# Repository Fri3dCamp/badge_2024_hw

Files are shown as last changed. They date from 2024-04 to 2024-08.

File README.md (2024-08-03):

# Badge 2024 hardware
In deze Git repository kan je de ontwerpbestanden en productiedata vinden van de [Fri3d Camp](https://fri3d.be/) 2024 badge. Revisie 01 is de versie die op kamp zal uitgedeeld worden.

De badge is gebouwd rond de **Espressif [ESP32-S3-WROOM-1-N16R8](Datasheets/esp32-s3-wroom-1_wroom-1u_datasheet_en.pdf) module** met :

- 16MB flash 
- 8MB PSRAM. 
- De [ESP32-S3](Datasheets/esp32-s3_datasheet_en.pdf) dual-core Xtensa LX7 microcontroller (geklokt aan 240MHz)
- Wi-Fi (via de ESP32-S3)
- Bluetooth 5 (via de ESP32-S3)

Omdat deze microcontroller zelf een USB interface heeft is er geen nood meer om een USB serial brug te voorzien zoals op de [badge van 2022]( https://github.com/Fri3dCamp/badge-2020) en de [badge van 2018]( https://github.com/Fri3dCamp/badge). 

We hebben de badge ook uitgerust met:

- [6-assige IMU van Würth Elektronik](Datasheets/Wurth-WSEN-ISDS.pdf)
- buzzer
- veel drukknoppen
- joystick
- microSD kaart lezer
- een prachtige [2” IPS LCD met afgeronde hoeken](Datasheets/QT020JA001-A0_SPEC.pdf).

Er is opnieuw een [tweede voeding](Datasheets/xc6210.pdf) geplaatst om de Wi-Fi module afzonderlijk van voeding te voorzien. In deze versie hadden we gelukkig genoeg vrije I/O om deze 2de voeding ook aan te kunnen sturen. Om energie te besparen kan je deze dus uitschakelen, enkel de ESP32-S3 zal dan nog stroom krijgen. 

Om het geheel van stroom te voorzien gebruiken we deze keer een [2000mAh lithium polymeer cel](Datasheets/2000mAh_704060_battery_Tewaycell.pdf) met een ingebouwd beschermingscircuit. Deze batterijen zijn mechanisch niet zo sterk als de 18650 cellen die we in vorige editie gebruikten, daarom heeft de badge standaard een cover om de batterij te beschermen. 

Om de batterij op te laden via de ingebouwde USB-C poort, maken we opnieuw gebruik van de [TP4056 lineaire lader](Datasheets/TP4056.pdf). 

Er is ook een aansluiting voor de [blaster]( https://github.com/Fri3dCamp/blaster_2024) ([die van 2022]( https://github.com/Fri3dCamp/timeblaster-2020) is ook compatibel met deze badge!). 

We hebben plek voorzien voor een [SAO header]( https://hackaday.com/2019/03/20/introducing-the-shitty-add-on-v1-69bis-standard/) en is er onderaan een eigen uitbreidingsconnector waar je makkelijk een draadje in kan steken om te experimenteren.

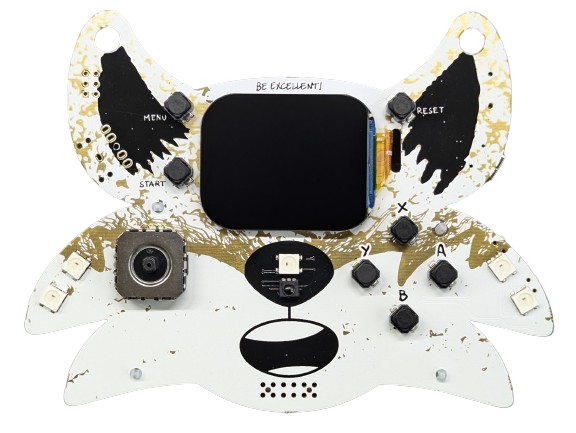
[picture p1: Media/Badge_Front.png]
Badge 2024 00 Front


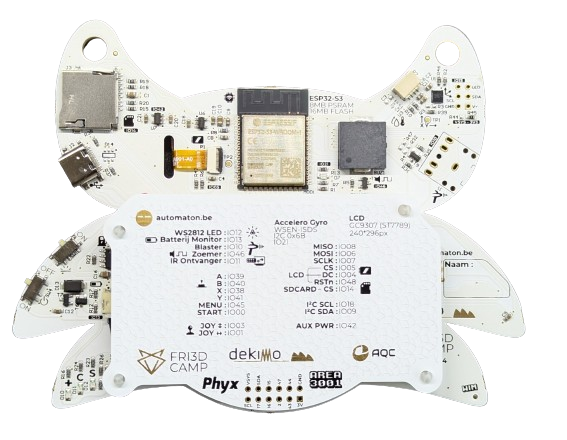
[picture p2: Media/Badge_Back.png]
Badge 2024 00 Back


Voor de liefhebbers heeft Yvan Barbaix ook een 3D model gemaakt om de joystick wat gebruiksvriendelijker te maken. Deze kan je terugvinden in de `3D` map.

# Badge 2024 hardware (EN)
This repository contains the hardware design and production files for the [Fri3d Camp](https://fri3d.be/en/) 2024 badge.
Revision 01 will be handed out during the event.

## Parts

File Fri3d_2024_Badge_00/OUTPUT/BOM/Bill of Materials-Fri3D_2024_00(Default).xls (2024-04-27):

Bill of Materials |  |  | Fri3D Badge 2024
Project: |  | Fri3D_2024_00.PrjPcb
Revision: |  | 00
Variant: |  | Default
Creation Date: | 12/11/2023 | 21:31
Print Date: | 2023-11-12 | 21:31:23
Footprint | Comment | LibRef | Designator | Value | Description | Supplier 1 | Supplier Part Number 1 | Supplier 2 | Supplier Part Number 2 | Supplier 3 | Supplier Part Number 3 | Quantity
CUI_CMT-1203-SMT | 12x12x3mm Piezo Buzzer Transducer 81dB | BUZ # CUI CMT-1203-SMT | BUZ1 | CMT-1203-SMT | BUZ # CUI CMT-1203-SMT | Digi-key | 102-2197-1-ND | LCSC | C409829 | LCSC | C391037 | 1
C0805_N |  | CAP # 10uF 10V 0805 | C1, C10, C16, C17 | 10uF 10V | CAP # 10uF 10V 0805 | Farnell | 2320859 | LCSC | C17024 | Generic | 10uF 10V 0805 X7R | 4
C0603_N |  | CAP # 100nF 16V 0603 | C2, C4, C6, C8, C9 | 100nF 16V | CAP # 100nF 16V 0603 | LCSC | C282519 |  |  | Generic | 100nF 16V 0603 X7R | 5
C0603_N |  | CAP # 1uF 16V 0603 | C5, C11, C12, C18, C19, C20, C21 | 1uF 16V | CAP # 1uF 16V 0603 | Farnell | 2320814 | LCSC | C1592 | Generic | 1uF 16V 0603 X7R | 7
LED_5050_WS2812B_WHITE | WS2812 based digital RGB LED 5050 White package reduced current | LED # RGB WS2812C-5050 WH | D1, D2, D3, D4, D5 | WS218C 5050 WH | LED # RGB WS2812C-5050 WH | Aliexpress | WS2812C Black 5050 | LCSC | C114587 |  |  | 5
LED_0805_RD | Default 0805 Red LED | LED # Red 0805 | D7, D11 |  | LED # Red 0805 | Farnell | 2099236 | LCSC | C965812 |  |  | 2
LED_0805_GR | Default 0805 Green LED | LED # Green 0805 | D10, D12 |  | LED # Green 0805 | Farnell | 2099239 | LCSC | C965815 |  |  | 2
SMA_AC | MBRA210LT3G Schottky Power Rectifier, 2A, 10V | Schottky # MBRA210LT3G | D13 | MBRA210LT3G | Schottky # MBRA210LT3G | LCSC | C145190 |  |  |  |  | 1
CHAU_ZIRM-5042B-42-Z2 | ZIRM-5042B-42-Z2 Infrared Receiver 38 kHz 45° 2.7-5.5V 940nm | PHO # IR Rx 940nm ZIRM-5042B-42-Z2 | D15 | ZIRM-5042B-42-Z2 | PHO # IR Rx 940nm ZIRM-5042B-42-Z2 | LCSC | C575386 |  |  |  |  | 1
XUNPU-TYPEC-304S-ACP16 | USB 2.0 C Reversible Receptacle Horizontal full SMD | USB # C 2.0 RCPT TYPEC-304S-ACP16 | J2 | TYPEC-304S-ACP16 | USB # C 2.0 RCPT TYPEC-304S-ACP16 | LCSC | C5187472 | LCSC | C2927040 | LCSC | C5156603 | 1
TFP09-2-12B | Micro SD PiPo Push-Push | MicroSD TFP09-2-12B Push-Push | J3 | TFP09-2-12B | MicroSD TFP09-2-12B Push-Push | AliExpress | TFP09-2-12B | LCSC | C393941 | LCSC | C381082 | 1
WE_709622400 | HIWA LCC-12 Snap-in - Snap-in 12.7mm | SPACER SNAP-SNAP LCC-12 -12.7mm | M1, M2, M3, M4 | LCC-12 | SPACER SNAP-SNAP LCC-12 -12.7mm | LCSC | C155856 |  |  |  |  | 4
ESP-ESP32-S3-WROOM-1 | ESP32-S3 based WROOM-1 16MB Flash, 8MB PSRAM | WiFi # MOD ESP32-S3-WROOM-1-N16R8 | MOD1 | ESP32-S3-WROOM-1-N16R8 | WiFi # MOD ESP32-S3-WROOM-1-N16R8 | Espressif | ESP32-S3-WROOM-1-N16R8 | Digi-key | 1965-ESP32-S3-WROOM-1-N16R8DKR-ND |  |  | 1
FPC_0.3K-HX-15PWB | Top contact FPC 0.3mm pitch 15 contacts | FPC # 15 Top 0.3mm 0.3K-HX-15PWB | P1 | 0.3K-HX-15PWB | FPC # 15 Top 0.3mm 0.3K-HX-15PWB | LCSC | C2919525 |  |  |  |  | 1
WE_665104131822 | Header 1.0mm RA Shrouded 4 | HDR # RA SHR 1.0mm 4way - 665104131822 | P2 | 665104131822 | HDR # RA SHR 1.0mm 4way - 665104131822 | Wurth | 665104131822 | Mouser | 710-665104131822 |  |  | 1
JST_ZH_S2B-ZR-SM4A-TF | Header RA 1.5mm Shrouded S2B-ZR-SM4A-TF | HDR # RA SHR 1.5mm 2way - S2B-ZR-SM4A-TF | P4 | S2B-ZR-SM4A-TF | HDR # RA SHR 1.5mm 2way - S2B-ZR-SM4A-TF | LCSC | C265329 | Farnell | 1830920 | Digi-Key | 455-1693-1-ND | 1
PSP_Mini_Joystick | PSP Mini Joystick | JOY # PSP Mini Joystick | P7 | PSP Mini Joystick | JOY # PSP Mini Joystick | AliExpress | 32958017132 |  |  |  |  | 1
WE_610312243021_POST | Receptacle 6x2 SMD low profile | Receptacle # 2.54mm dual row 12way 610312243021 | P10 | 610312243021 | Receptacle # 2.54mm dual row 12way 610312243021 | Wurth | 610312243021 | Mouser | 710-610312243021 |  |  | 1
R0603_N |  | RES # 10K 0603 | R1, R15, R18, R19, R20 | 10K | RES # 10K 0603 | Farnell | 2502397 | LCSC | C25804 | Generic | 10K 1% 0603 | 5
R0603_N |  | RES # 5K1 0603 | R2, R7, R8, R9, R10, R21, R35, R36, R37, R38 | 5K1 | RES # 5K1 0603 | Farnell | 2845922 | LCSC | C112314 | Generic | 5K1 1% 0603 | 10
R0603_N |  | RES # 100K 0603 | R5, R12, R17, R25, R26 | 100K | RES # 100K 0603 |  |  |  |  | Generic | 100K 1% 0603 | 5
R0603_N |  | RES # 100R 0603 | R6, R39, R43, R46 | 100R | RES # 100R 0603 | Farnell | 2446544 |  |  | Generic | 100R 1% 0603 | 4
R0603_N |  | RES # 1K2 0603 | R11, R13, R16, R22, R23, R24 | 1K2 | RES # 1K2 0603 | Farnell | 2446592 |  |  | Generic | 1K2 1% 0603 | 6
R0402 |  | NTC # 10K 0402 | R27 | 10K | NTC # 10K 0402 | LCSC | C209959 | LCSC | C98099 |  |  | 1
R0603_N |  | RES # 0R 0603 | R45 | 0R | RES # 0R 0603 | Farnell | 2447743 | LCSC | C95177 | Generic | 0R 1% 0603 | 1
WE_450404015514 | WS-SLSU Mini slide switch 1P2T SMD | SW # 1P2T WS-SLSU mini slide 6,7 x 2,7 mm | SW1, SW4 | 450404015514 | SW # 1P2T WS-SLSU mini slide 6,7 x 2,7 mm | Digi-key | 732-13665-1-ND | LCSC | C431540 |  |  | 2
ALPS_SKPMAME010 | SKPMAME010 6x6 TACTG Switch | SW # TACT ALPS SKPMAME010 | SW5, SW6, SW7, SW8, SW9, SW10, SW11 | SKPMAME010 | SW # TACT ALPS SKPMAME010 | LCSC | C115348 | Farnell | 2056804 | Mouser | 688-SKPMAM | 7
SOT23-3 | 0.2A N-Ch MOSFET Vgs 3.2 | BSS138 N-Ch MOSFET 0.2A 3.2Vgs 60Vds | T1, T9 | BSS138 |  | Farnell | 2432717 |  |  |  |  | 2
SOT23-3 | -2.3A -20V P-Ch MOSFET Vgs -1V | SL2301 P-Ch MOSFET -2.3A -20Vds | T6, T7 | SL2301 | SL2301 P-Ch MOSFET -2.3A -20Vds | LCSC | C181086 |  |  |  |  | 2
TP_1.2mm |  | TP # 1.2mm | TP1, TP2 | NO BOM | TP # 1.2mm |  |  |  |  |  |  | 2
WE_2536030320001 | Acceleration ±2, ±4, ±8, ±16g Gyro ±125, ±250, ±500, ±1000, ±2000dps | ACCELERO GYRO # WSEN-ISDS | U1 | 2536030320001 | ACCELERO GYRO # WSEN-ISDS | Würth | 2536030320001 |  |  |  |  | 1
SOIC_N_8_TH | Single Cell LiIon charger max 1A | CHG # TP4056 LiIon 1A | U5 | TP4056 | CHG # TP4056 LiIon 1A | Aliexpress | TP4056 | LCSC | C382139 |  |  | 1
SOT23-5 | 3V3 LDO 700mA 50mV | LDO # 3V3 XC6210B33 | U6, U7 | XC6210B332MR | LDO # 3V3 XC6210B33 | Farnell | 1057803 | LCSC | C47719 |  |  | 2
 |  |  |  |  |  |  |  |  |  |  |  | 91
Approved |  | Notes

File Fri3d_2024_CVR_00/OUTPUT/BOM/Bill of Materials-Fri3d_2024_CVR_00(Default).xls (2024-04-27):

Bill of Materials |  |  | Fri3D Badge 2024 CVR
Project: |  | Fri3d_2024_CVR_00.PrjPcb
Revision: |  | 00
Variant: |  | Default
Creation Date: | 16/04/2024 | 23:12
Print Date: | 2024-04-27 | 21:48:27
Footprint | Comment | LibRef | Designator | Value | Description | Supplier 1 | Supplier Part Number 1 | Supplier 2 | Supplier Part Number 2 | Supplier 3 | Supplier Part Number 3 | Quantity
C0603_N |  | CAP # 100nF 16V 0603 | C1 | 100nF 16V | CAP # 100nF 16V 0603 | LCSC | C282519 |  |  | Generic | 100nF 16V 0603 X7R | 1
C0603_N |  | CAP # 1uF 16V 0603 | C2, C3, C4, C5 | 1uF 16V | CAP # 1uF 16V 0603 | Farnell | 2320814 | LCSC | C1592 | Generic | 1uF 16V 0603 X7R | 4
LED_4020_WS2812B_WHITE | WS2812 based digital RGB LED 4020 White package Side emitting | LED # RGB WS2812B-4020 WH RA | D1, D2, D3, D4, D5, D6, D7, D8, D9, D10, D11 | WS218B 4020 WH RA | LED # RGB WS2812B-4020 WH RA | LCSC | C965557 |  |  |  |  | 11
HDR2X6 | Header 6X2 | Pin Header 2.54mm dual row 12way | P1 |  | Pin Header 2.54mm dual row 12way |  |  |  |  |  |  | 1
R0402 |  | RES # 0R 0402 | R1 | 0R | RES # 0R 0402 | Farnell | 2072513 |  |  | Generic | 0R 1% 0402 | 1
TI_DCK_R-PDSO-G5 | SN74AHCT1G125DCKR Buffer, Tri-State, 4.5V to 5.5V | BUF # 1 SN74AHCT1G125DCKR | U1 | SN74AHCT1G125DCKR | BUF # 1 SN74AHCT1G125DCKR | LCSC | C151417 | LCSC | C350557 |  |  | 1
 |  |  |  |  |  |  |  |  |  |  |  | 19
Approved |  | Notes

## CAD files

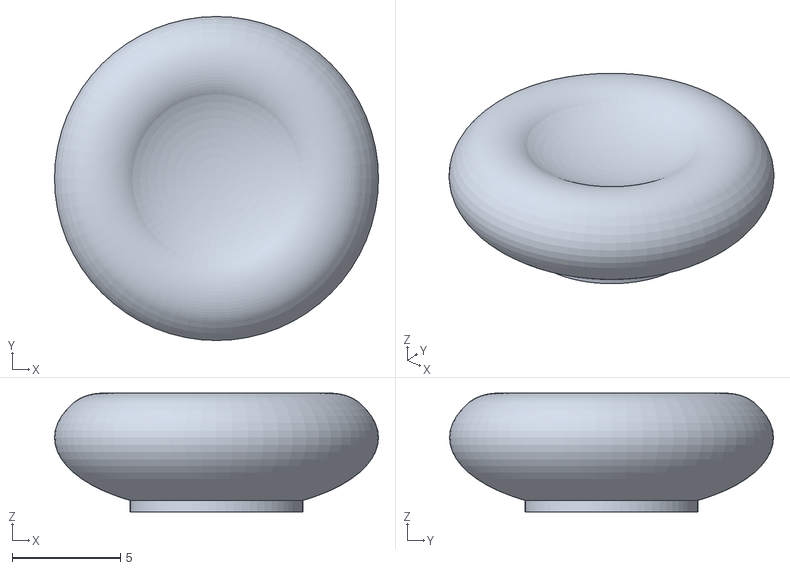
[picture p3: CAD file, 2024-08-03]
3D/joystick.stl
15.0 x 15.0 x 5.50

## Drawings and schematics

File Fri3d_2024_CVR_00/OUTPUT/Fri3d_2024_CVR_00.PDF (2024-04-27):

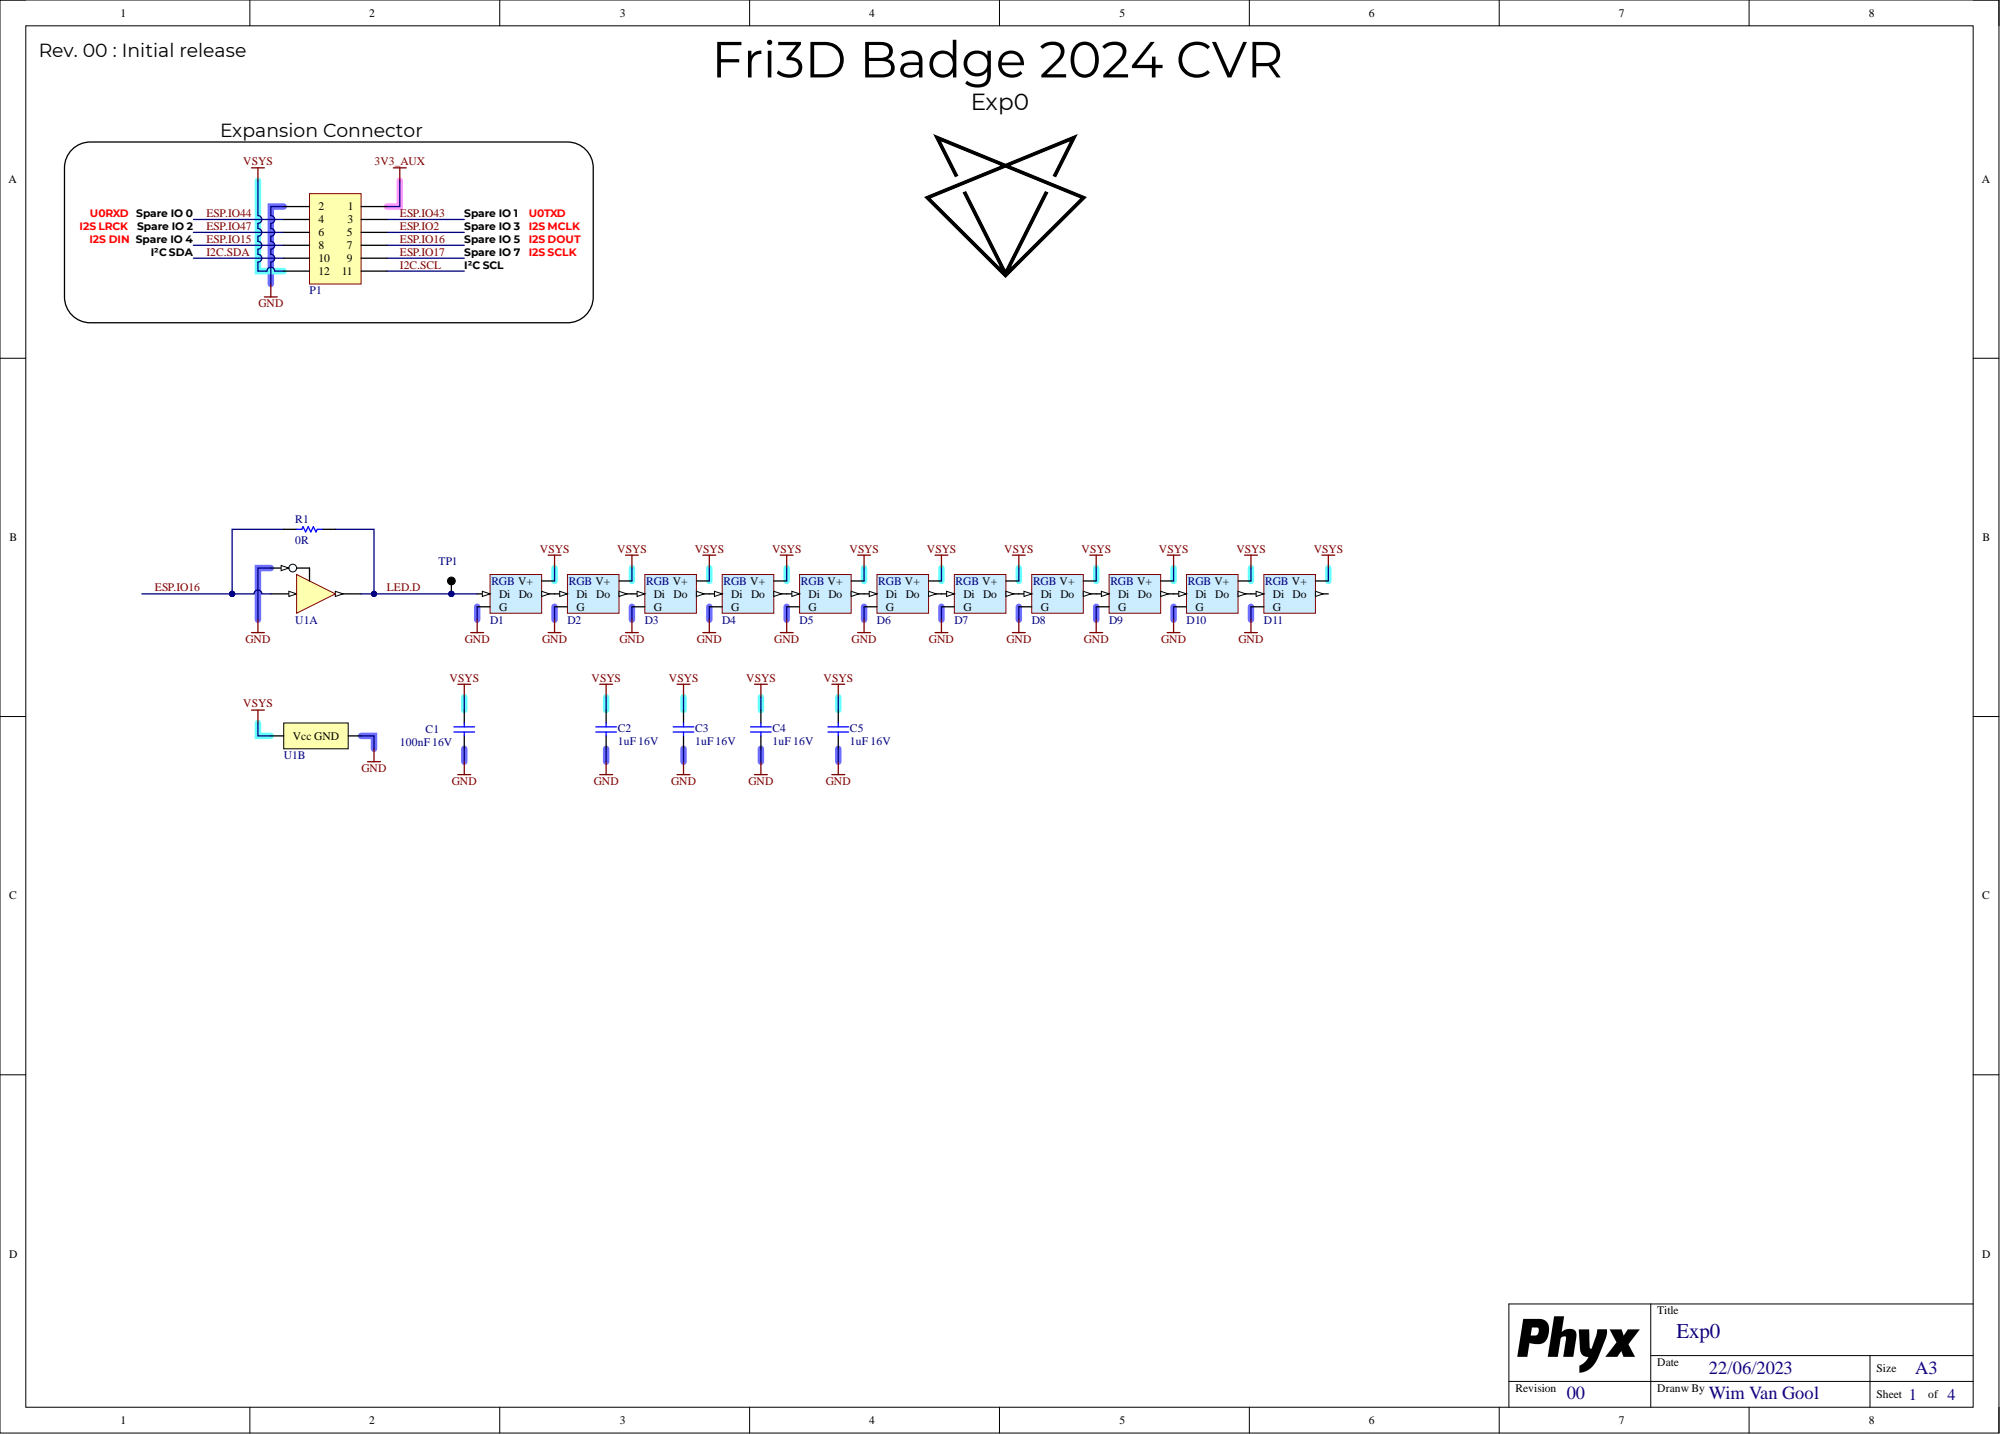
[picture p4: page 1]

Fri3D Badge 2024 CVR Rev. 00 : Initial release

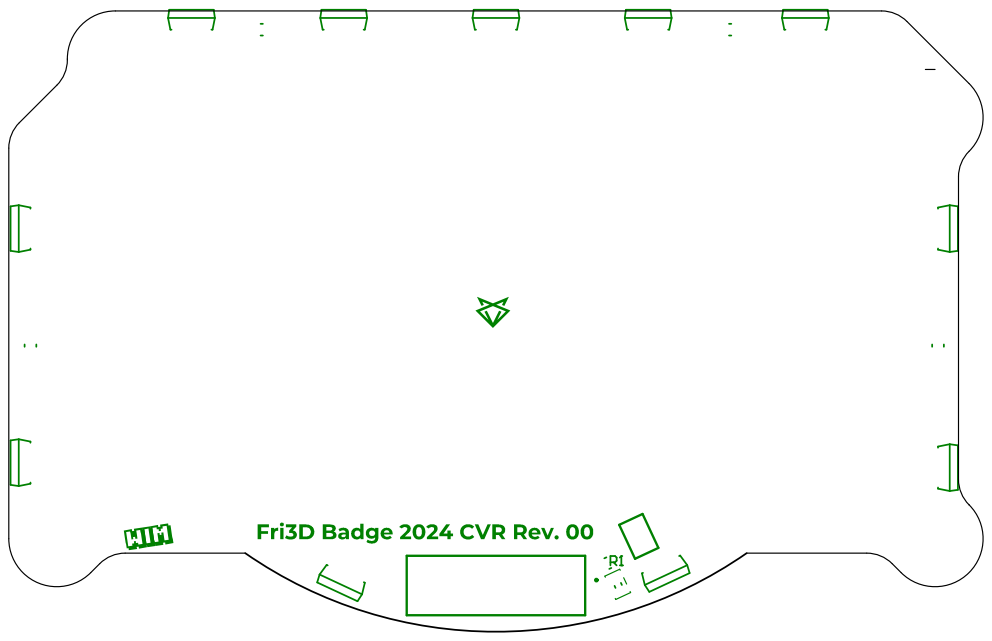
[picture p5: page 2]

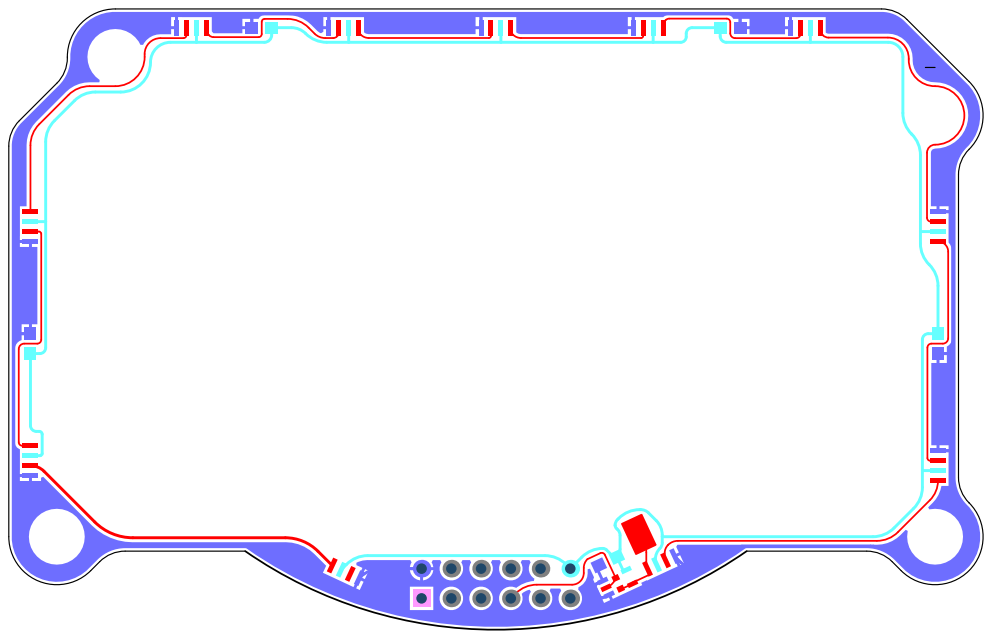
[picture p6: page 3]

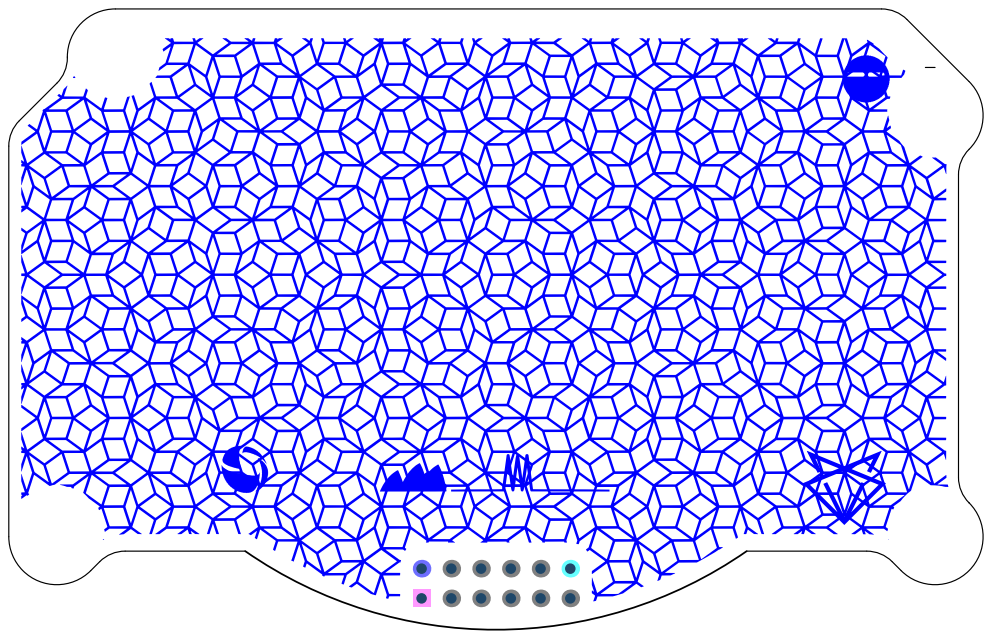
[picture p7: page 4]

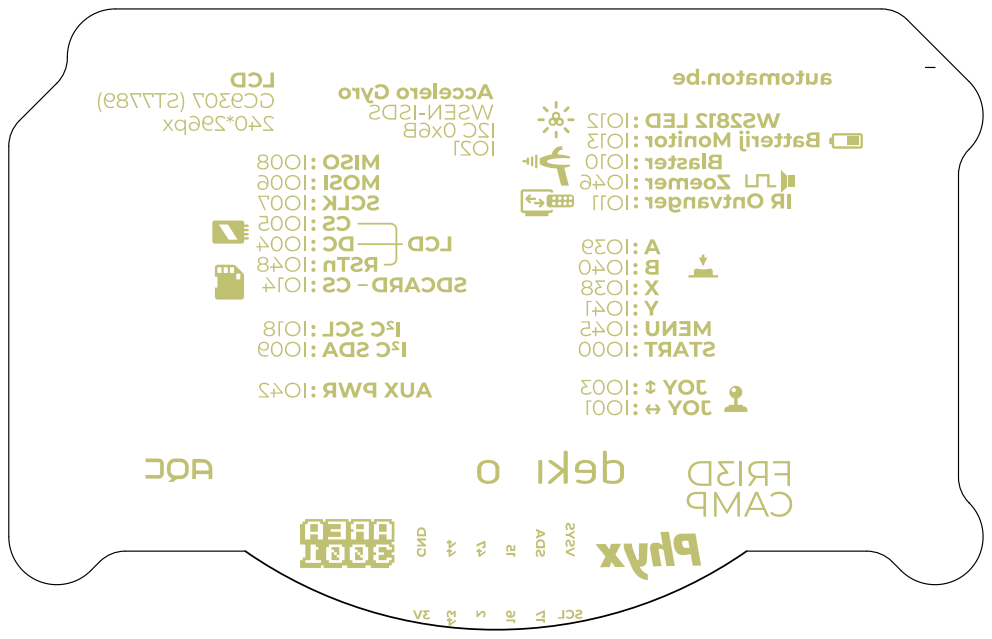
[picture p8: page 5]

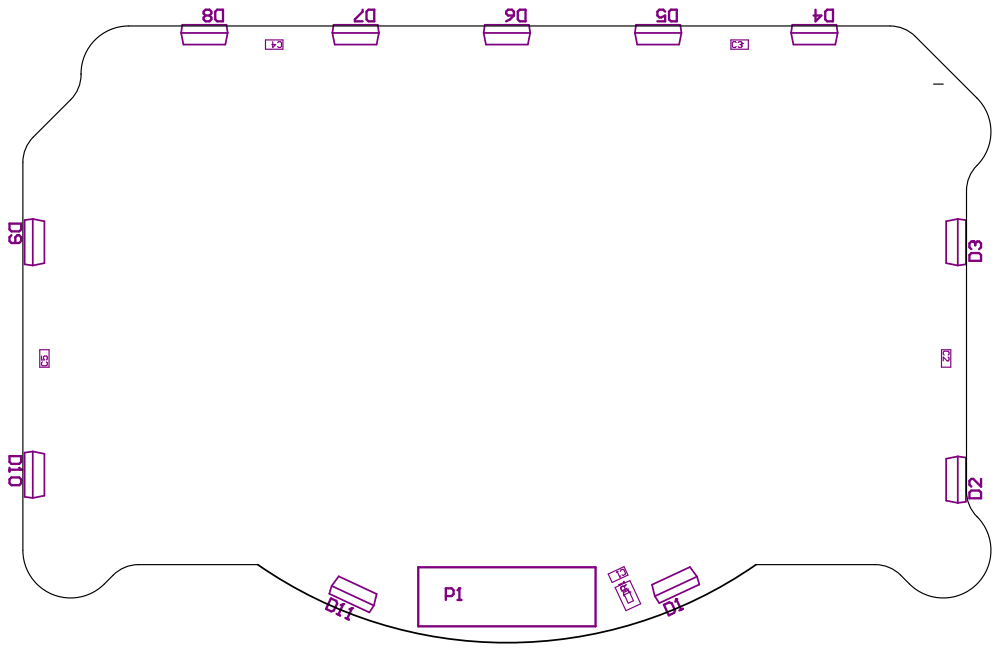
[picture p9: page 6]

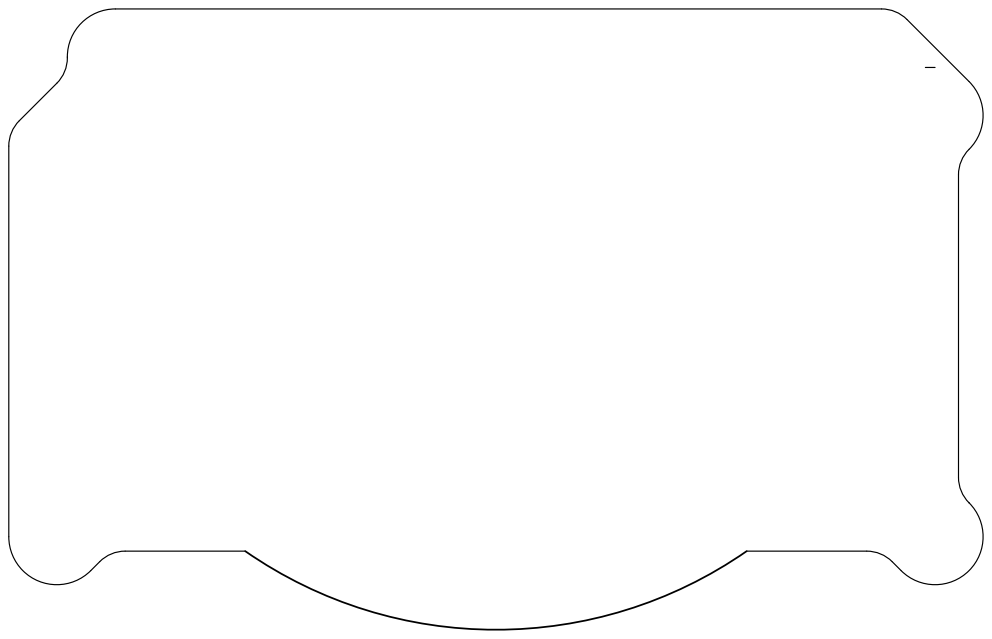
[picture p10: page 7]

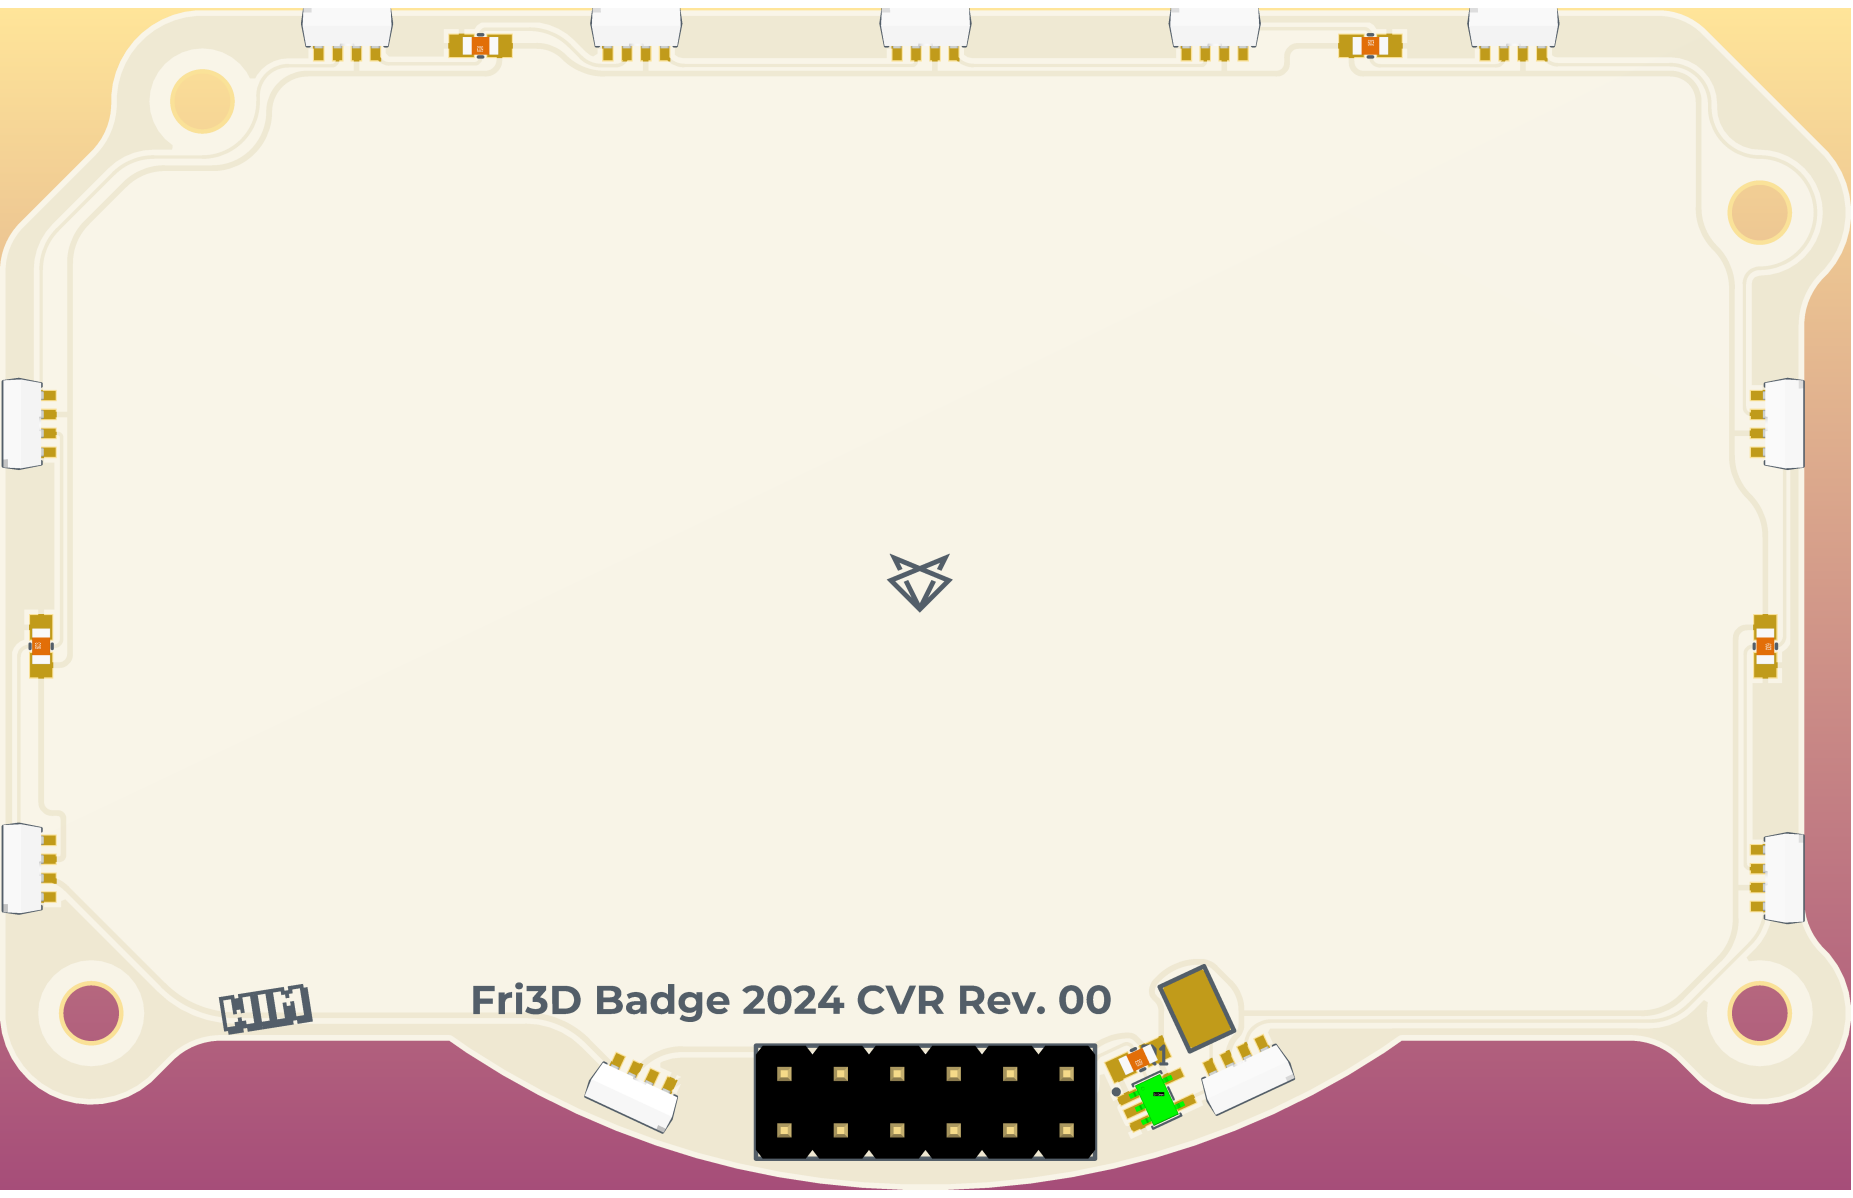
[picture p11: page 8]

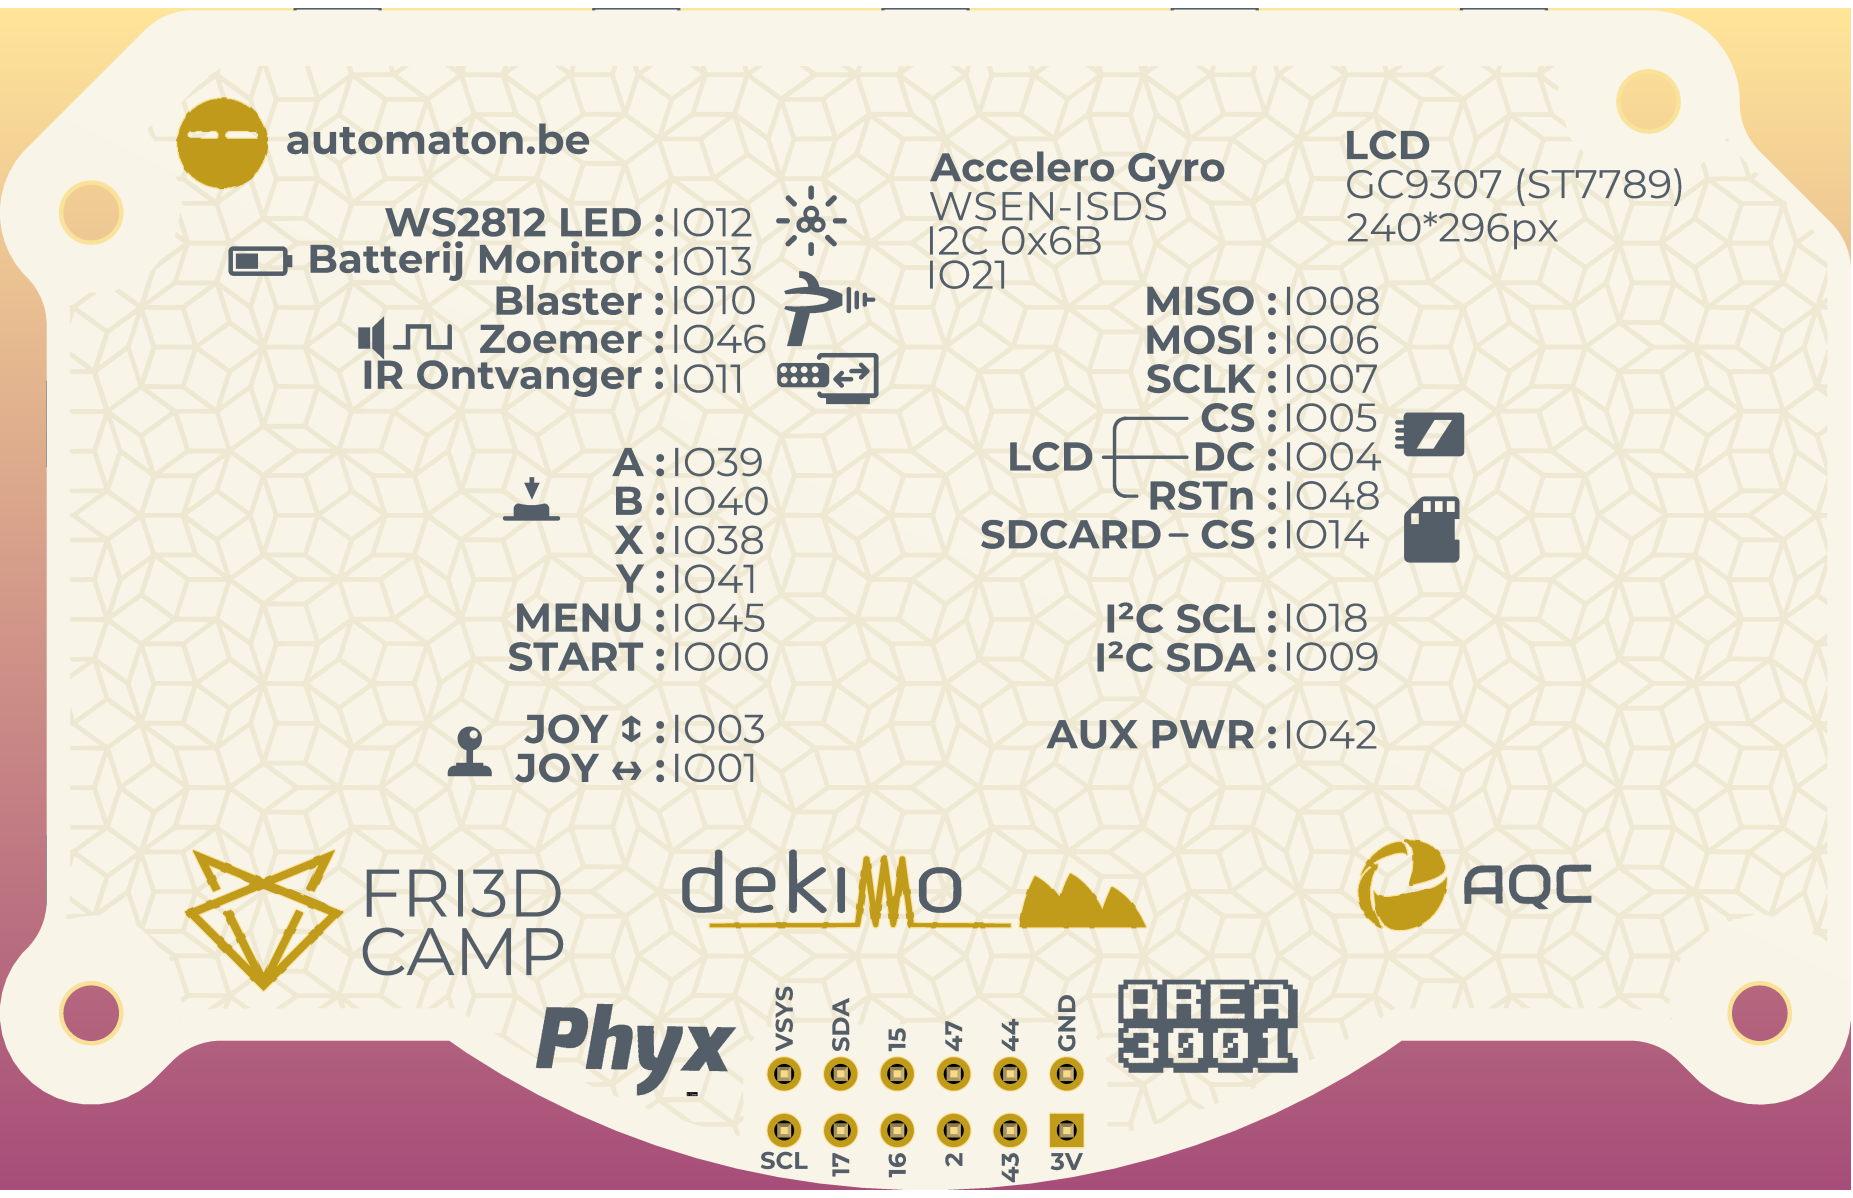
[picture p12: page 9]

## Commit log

2024-04-27 Design files & draft of readme
    Initial commit of Rev.00, Rev.01 design files of the badge. Rev.00 design files of the cover and the datasheets.
    [Bill of Materials-Fri3D_2024_00(Default).xls, Bill of Materials-Fri3D_2024_01(Default).xls, Bill of Materials-Fri3d_2024_CVR_00(Default).xls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]
2024-04-27 fixed typo
    Fixed autocorrect issue in link to battery datasheet
2024-04-27 fixed battery datasheet file name
    battery datasheet contains spaces, messes with MD links
2024-08-03 3D model added
    [joystick.stl]
